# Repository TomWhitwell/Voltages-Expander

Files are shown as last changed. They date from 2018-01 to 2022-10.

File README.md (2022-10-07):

# Voltages Expander for the Turing Machine 

Hardware documentation for the old Voltages Fader Expander for the Music Thing Modular Turing Machine, published CC-BY-SA. 

For more details, visit http://www.musicthing.co.uk/

Qty | Value | Device | Parts | Description | Mouser
-- | -- | -- | -- | -- | --
8 | 50k | Illuminated Fader | GATE1, GATE2, GATE3, GATE4, GATE5, GATE6, GATE7, GATE8 | 20mm Alpha Illuminated Fader | 312-2045F-R50K
1 | 10k | 9mm pot | SCALE | 9 mm vertical pot, D shaft | 688-RK09K1130AH1
1 | 50k | 9mm pot | OFFSET | 9 mm vertical pot, D shaft | 652-PTV09A-4025FB503
2 | 100n | C-EU025-024X044 | C1, C2 | CAPACITOR | 594-K104K15X7RF5TH5
1 | TL074 | TL074 | IC1 | OP AMP | 595-TL074CN
1 |   | MA08-2 | GATES | PIN HEADER 2x8 | 649-67997-216HLF
1 | 78L09 |   | 78L1 | Positive VOLTAGE REGULATOR | 511-L78L09ACZ
6 | 10k | R-EU_0207/10 | R3, R4, R5, R6, R7, R8 | RESISTOR | 660-MF1/4DCT52A1002F
4 | 1k | R-EU_0207/10 | R1, R2, R9, R10 | RESISTOR | 660-MF1/4DCT52R1001F
1 | 10k | RN08 | RN1 | Resistor Network 9 pin, 8 resistors, bussed | 652-4609X-1LF-10K
1 | 2k | RN08 | RN2 | Resistor Network 9 pin, 8 resistors, bussed | 652-4609X-1LF-2K
3 | PJ-301B | PJ-301B | CLOCK_OUT, INVERT_OUT, MAIN_OUT | Sockets | Available from Erthenvar or Thonk
1 |   |   | 14 pin DIP socket |   | 649-DILB14P-223TLF
  |   |   |   |   |

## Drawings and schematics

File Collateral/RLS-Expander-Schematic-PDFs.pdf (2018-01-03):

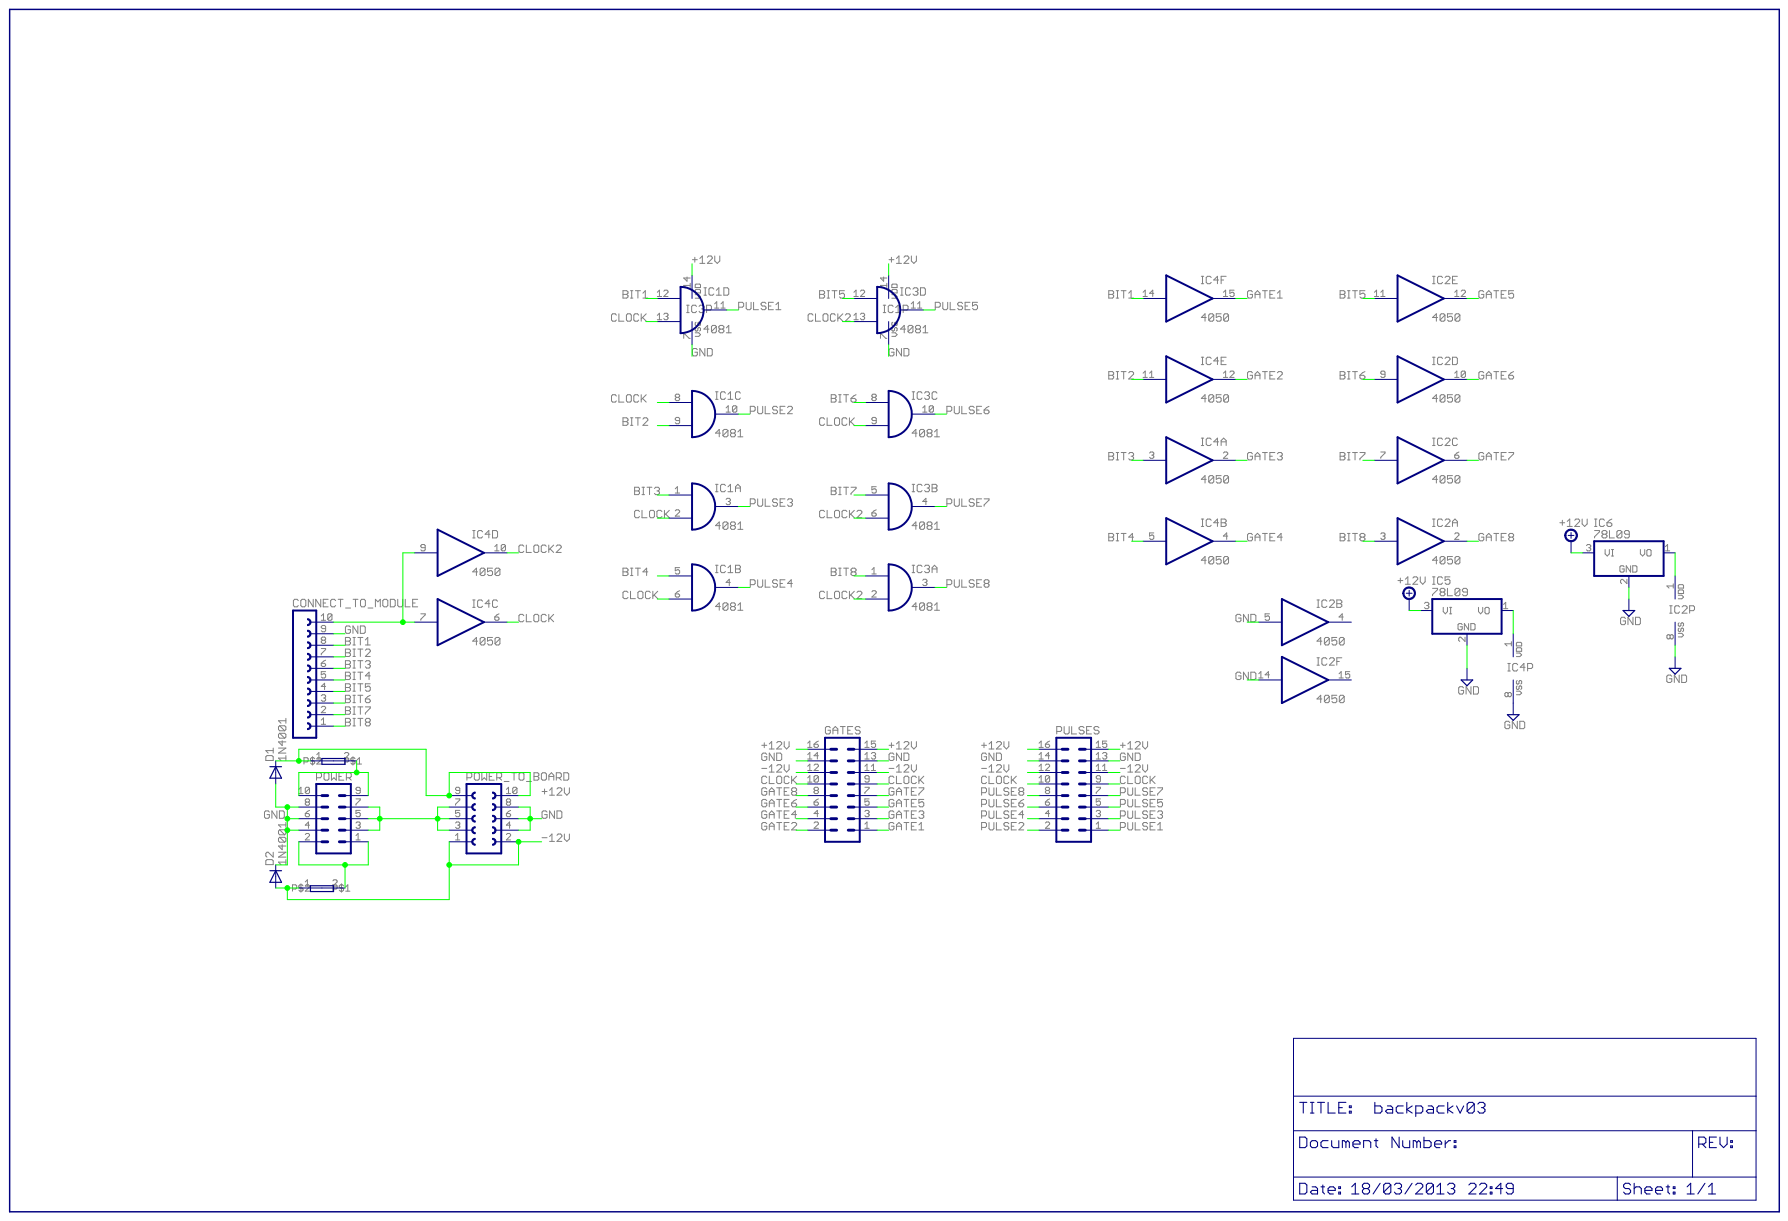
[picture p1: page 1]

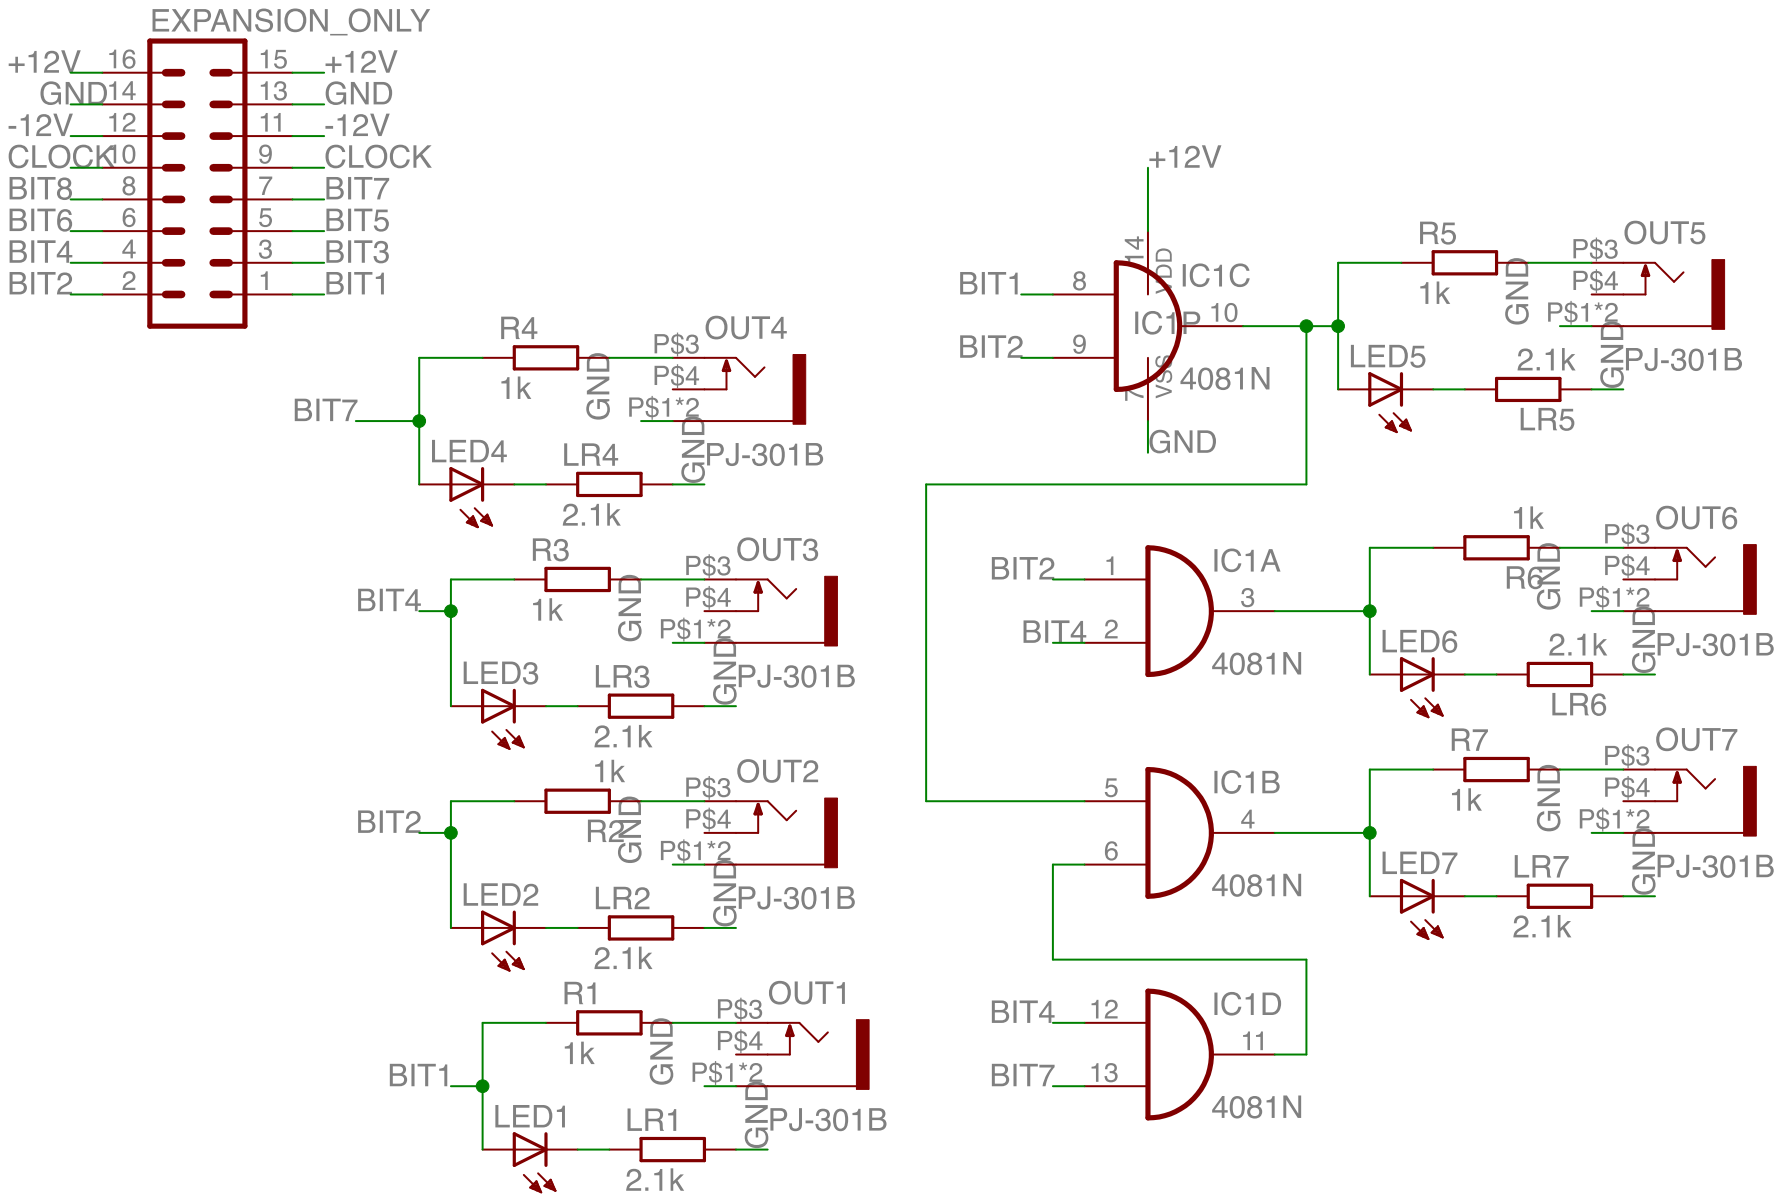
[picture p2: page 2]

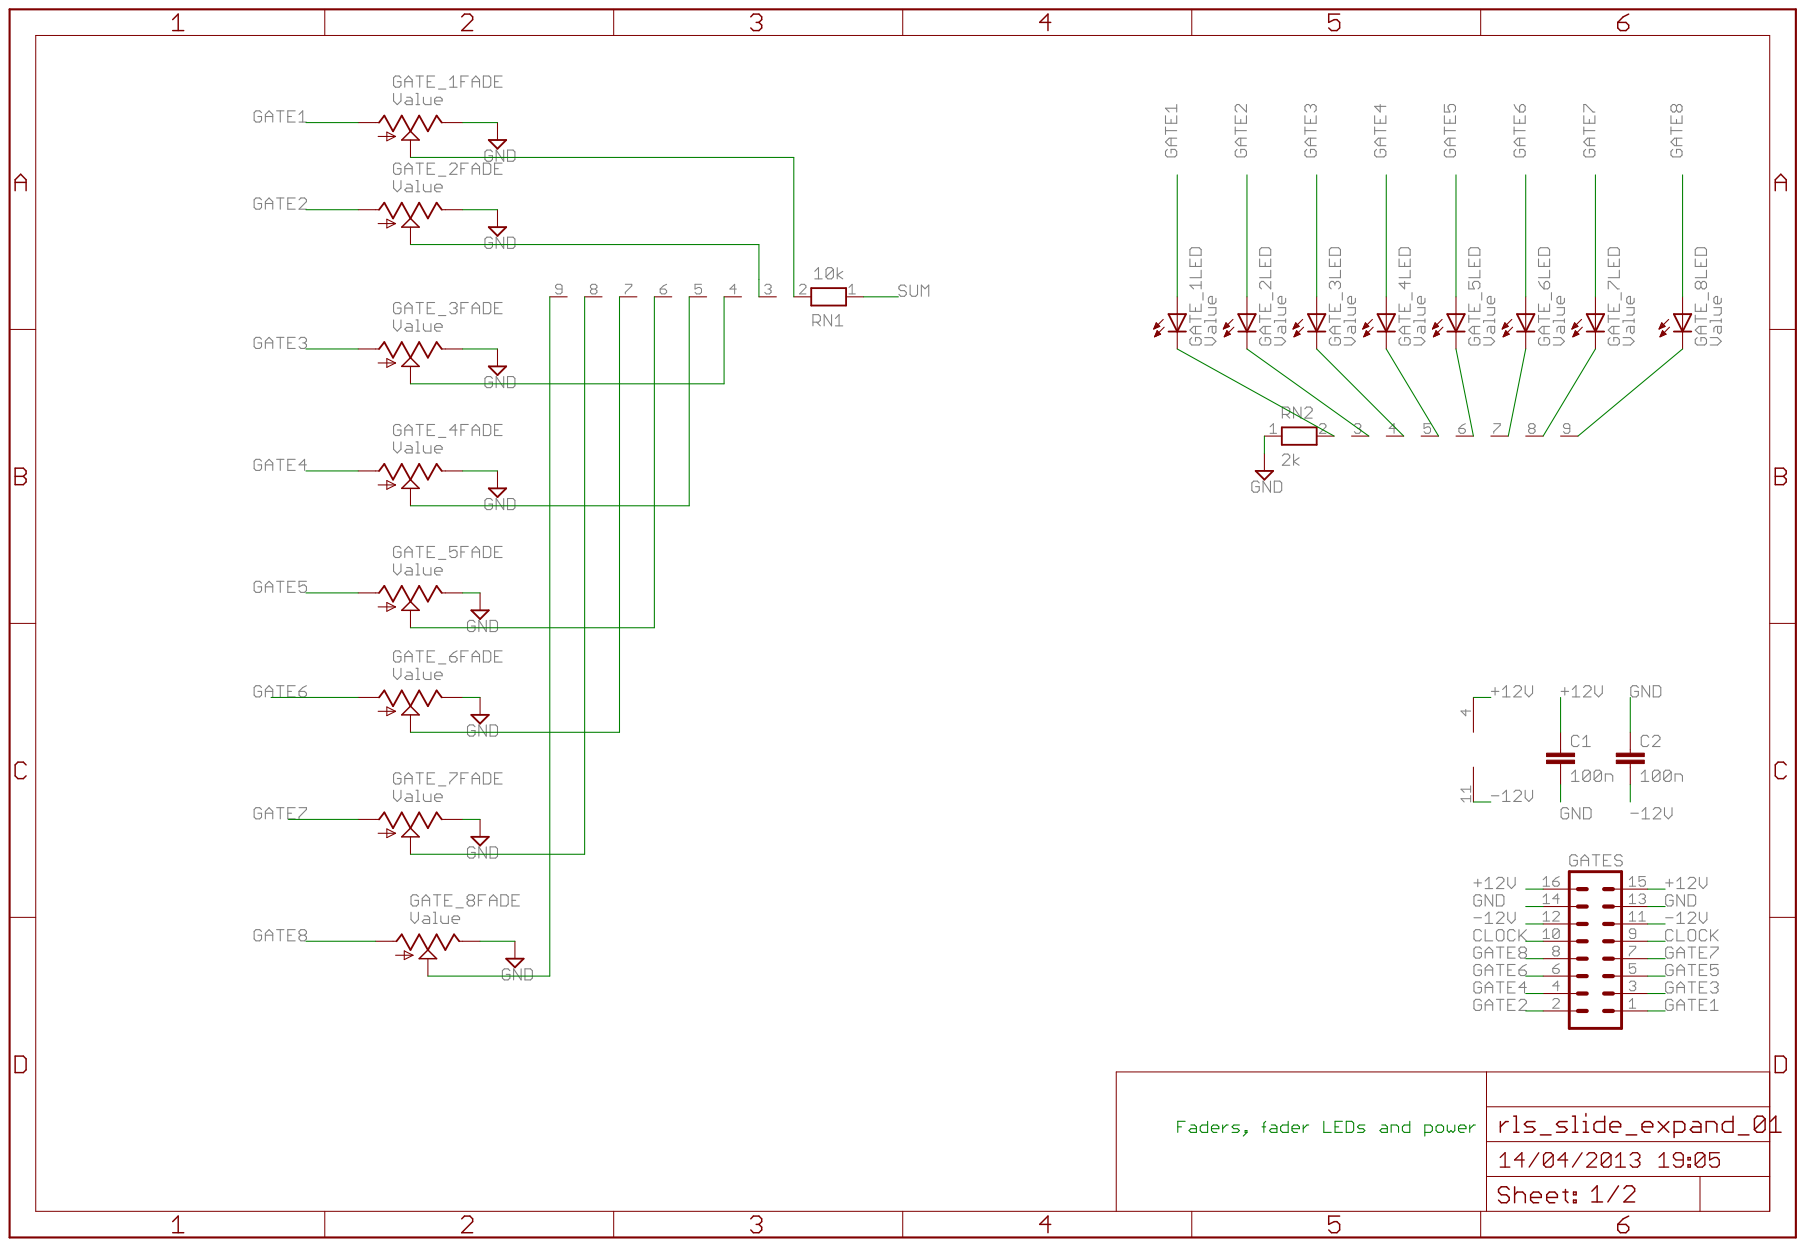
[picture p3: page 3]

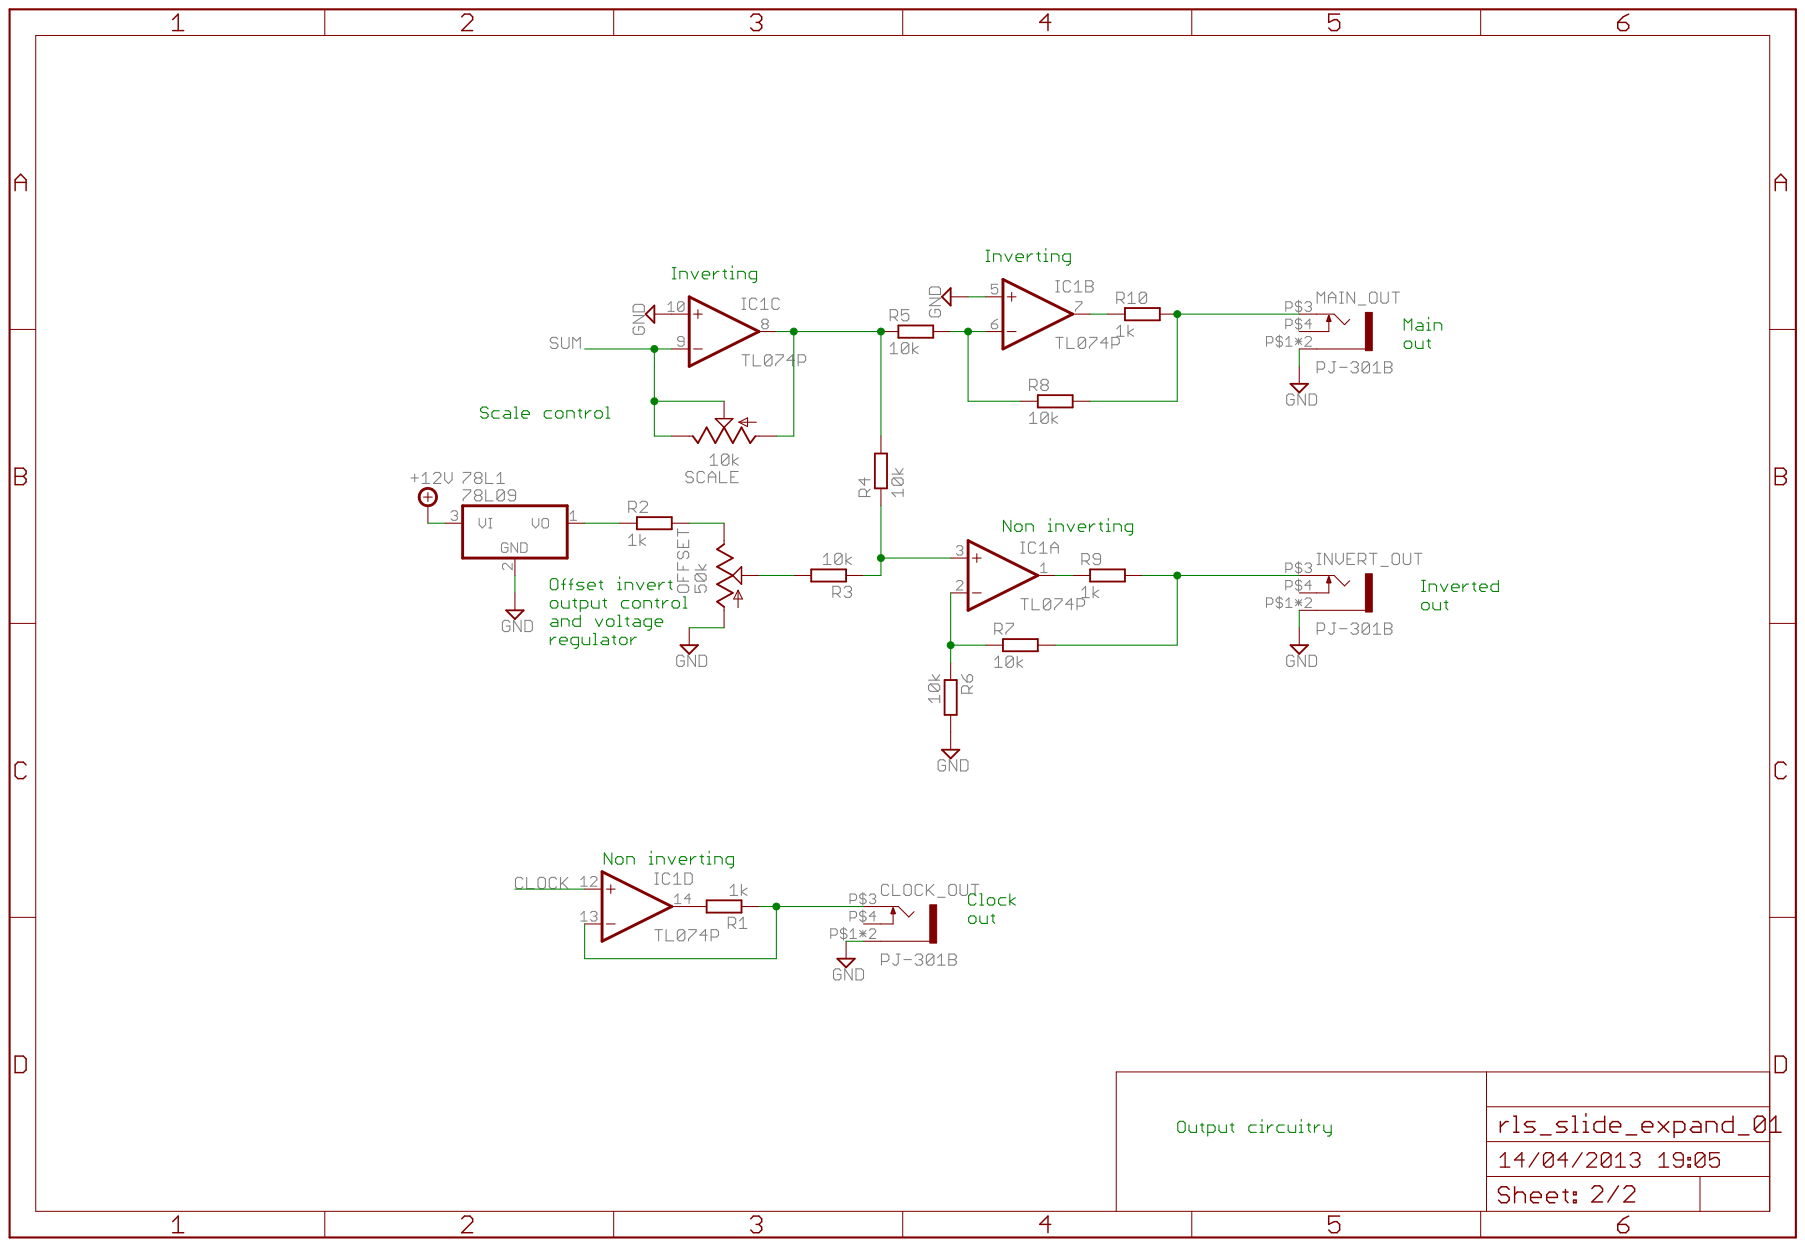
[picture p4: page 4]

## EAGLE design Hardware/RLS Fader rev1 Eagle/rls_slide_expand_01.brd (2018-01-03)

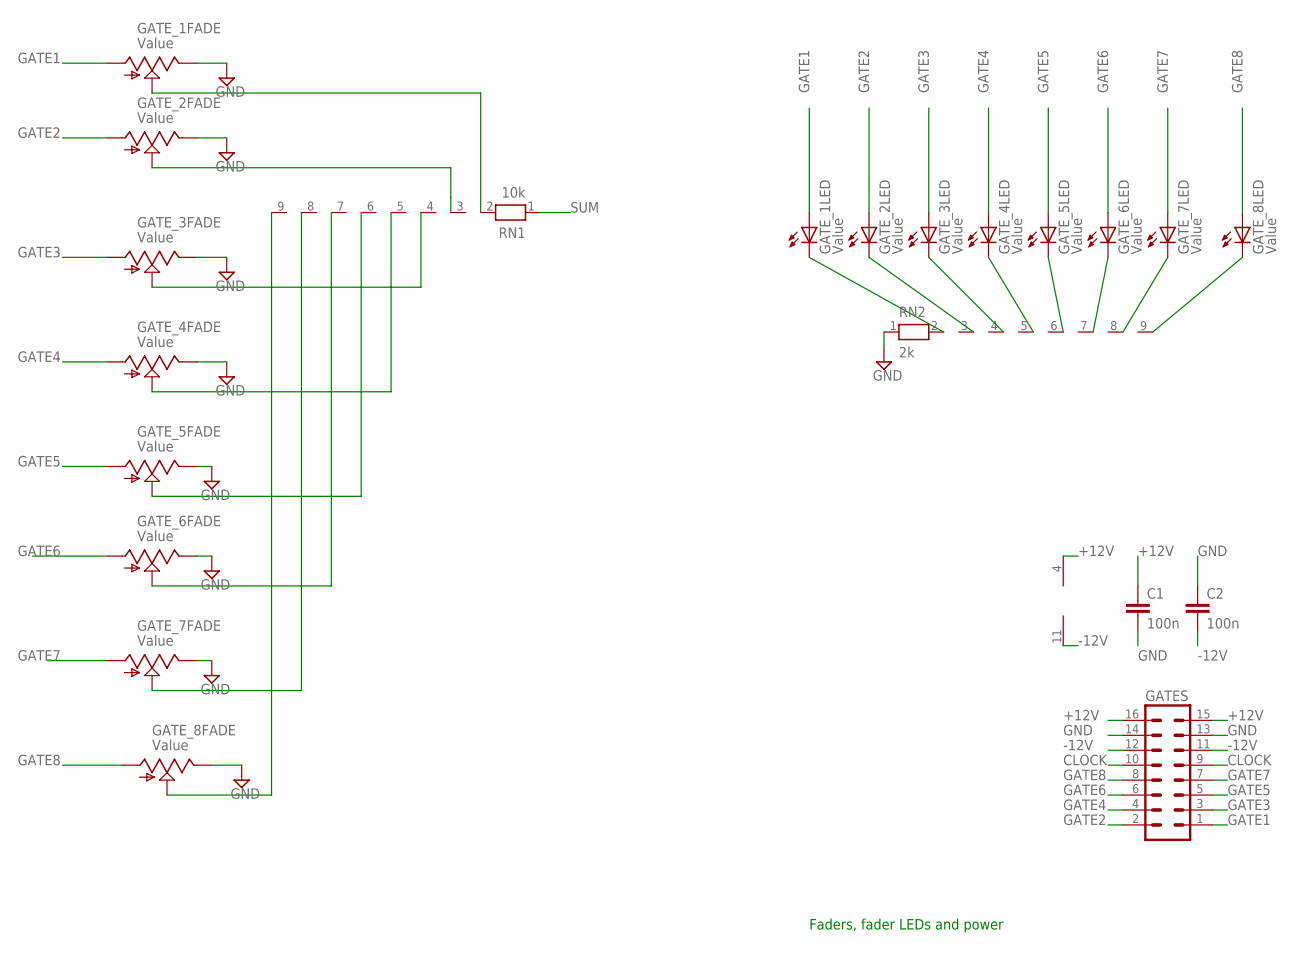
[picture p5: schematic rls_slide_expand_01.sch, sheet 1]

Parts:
C1, C2: 100n; C050-024X044
GATES: MA08-2
GATE_1, GATE_2, GATE_3, GATE_4, GATE_5, GATE_6, GATE_7, GATE_8: Value; ALPHA_ILL_FADER_20MM
IC1: TL074P; DIL14
RN1: 10k; RN-9
RN2: 2k; RN-9

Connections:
+12V: C1.1, GATES.15, GATES.16, IC1.4 (V+); also elsewhere on the board
-12V: C2.2, GATES.11, GATES.12, IC1.11 (V-)
CLOCK: GATES.9, GATES.10; also elsewhere on the board
GATE1: GATES.1, GATE_1.3 (A), GATE_1.B (A)
GATE2: GATES.2, GATE_2.3 (A), GATE_2.B (A)
GATE3: GATES.3, GATE_3.3 (A), GATE_3.B (A)
GATE4: GATES.4, GATE_4.3 (A), GATE_4.B (A)
GATE5: GATES.5, GATE_5.3 (A), GATE_5.B (A)
GATE6: GATES.6, GATE_6.3 (A), GATE_6.B (A)
GATE7: GATES.7, GATE_7.3 (A), GATE_7.B (A)
GATE8: GATES.8, GATE_8.3 (A), GATE_8.B (A)
GND: C1.2, C2.1, GATES.13, GATES.14, GATE_1.1 (E), GATE_2.1 (E), GATE_3.1 (E), GATE_4.1 (E), GATE_5.1 (E), GATE_6.1 (E), GATE_7.1 (E), GATE_8.1 (E), RN2.1; also elsewhere on the board
unnamed: GATE_1.2 (S), RN1.2
unnamed: GATE_1.E (C), RN2.2
unnamed: GATE_2.2 (S), RN1.3
unnamed: GATE_2.E (C), RN2.3
unnamed: GATE_3.E (C), RN2.4
unnamed: GATE_3.2 (S), RN1.4
unnamed: GATE_4.2 (S), RN1.5
unnamed: GATE_5.2 (S), RN1.6
unnamed: GATE_6.2 (S), RN1.7
unnamed: GATE_7.2 (S), RN1.8
unnamed: GATE_8.2 (S), RN1.9
unnamed: GATE_4.E (C), RN2.5
unnamed: GATE_6.E (C), RN2.7
unnamed: GATE_5.E (C), RN2.6
unnamed: GATE_7.E (C), RN2.8
unnamed: GATE_8.E (C), RN2.9
SUM: RN1.1; also elsewhere on the board

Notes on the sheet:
Faders, fader LEDs and power

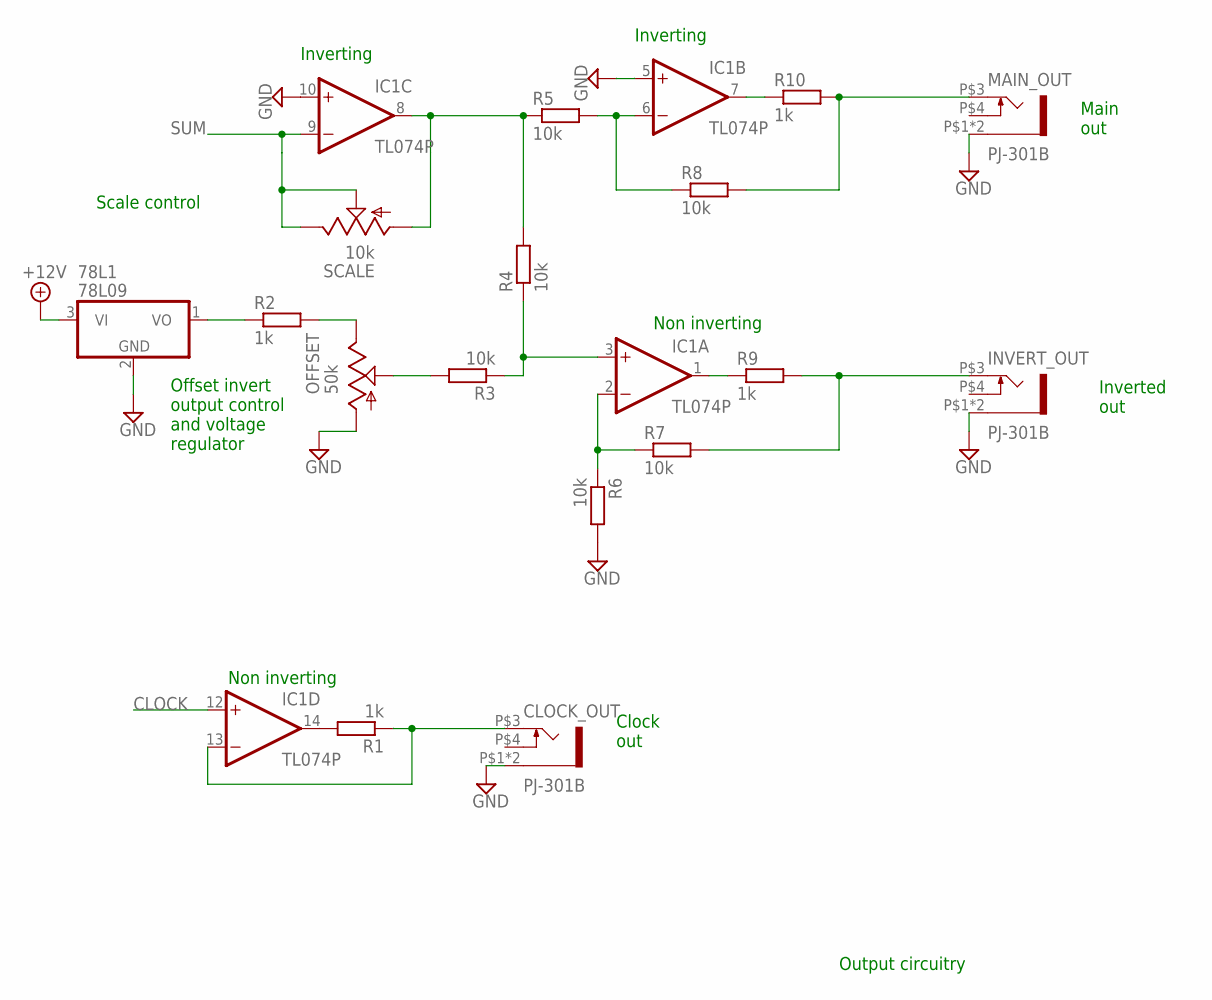
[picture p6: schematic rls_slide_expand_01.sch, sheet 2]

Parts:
78L1: 78L09; TO92
CLOCK_OUT: PJ-301B
IC1: TL074P; DIL14
INVERT_OUT: PJ-301B
MAIN_OUT: PJ-301B
OFFSET: 50k; EVUF
R1, R2, R9, R10: 1k; 0207/10
R3, R4, R5, R6, R7, R8: 10k; 0207/10
SCALE: 10k; EVUF

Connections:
+12V: 78L1.3 (VI); also elsewhere on the board
CLOCK: IC1.12 (+IN); also elsewhere on the board
GND: 78L1.2 (GND), CLOCK_OUT.P$1 (5), CLOCK_OUT.P$2 (5), IC1.5 (+IN), IC1.10 (+IN), INVERT_OUT.P$1 (5), INVERT_OUT.P$2 (5), MAIN_OUT.P$1 (5), MAIN_OUT.P$2 (5), OFFSET.1 (A), R6.2; also elsewhere on the board
unnamed: IC1.6 (-IN), R5.2, R8.1
unnamed: MAIN_OUT.P$3 (3), R8.2, R10.2
unnamed: IC1.7 (OUT), R10.1
unnamed: OFFSET.3 (E), R2.2
unnamed: IC1.1 (OUT), R9.1
unnamed: OFFSET.2 (S), R3.2
unnamed: IC1.3 (+IN), R3.1, R4.1
unnamed: IC1.2 (-IN), R6.1, R7.1
unnamed: INVERT_OUT.P$3 (3), R7.2, R9.2
unnamed: IC1.8 (OUT), R4.2, R5.1, SCALE.1 (A)
unnamed: IC1.14 (OUT), R1.2
unnamed: CLOCK_OUT.P$3 (3), IC1.13 (-IN), R1.1
unnamed: 78L1.1 (VO), R2.1
SUM: IC1.9 (-IN), SCALE.2 (S), SCALE.3 (E); also elsewhere on the board

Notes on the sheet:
Scale control
Offset invert output control and voltage regulator
Main out
Inverted out
Clock out
Output circuitry
Inverting
Non inverting

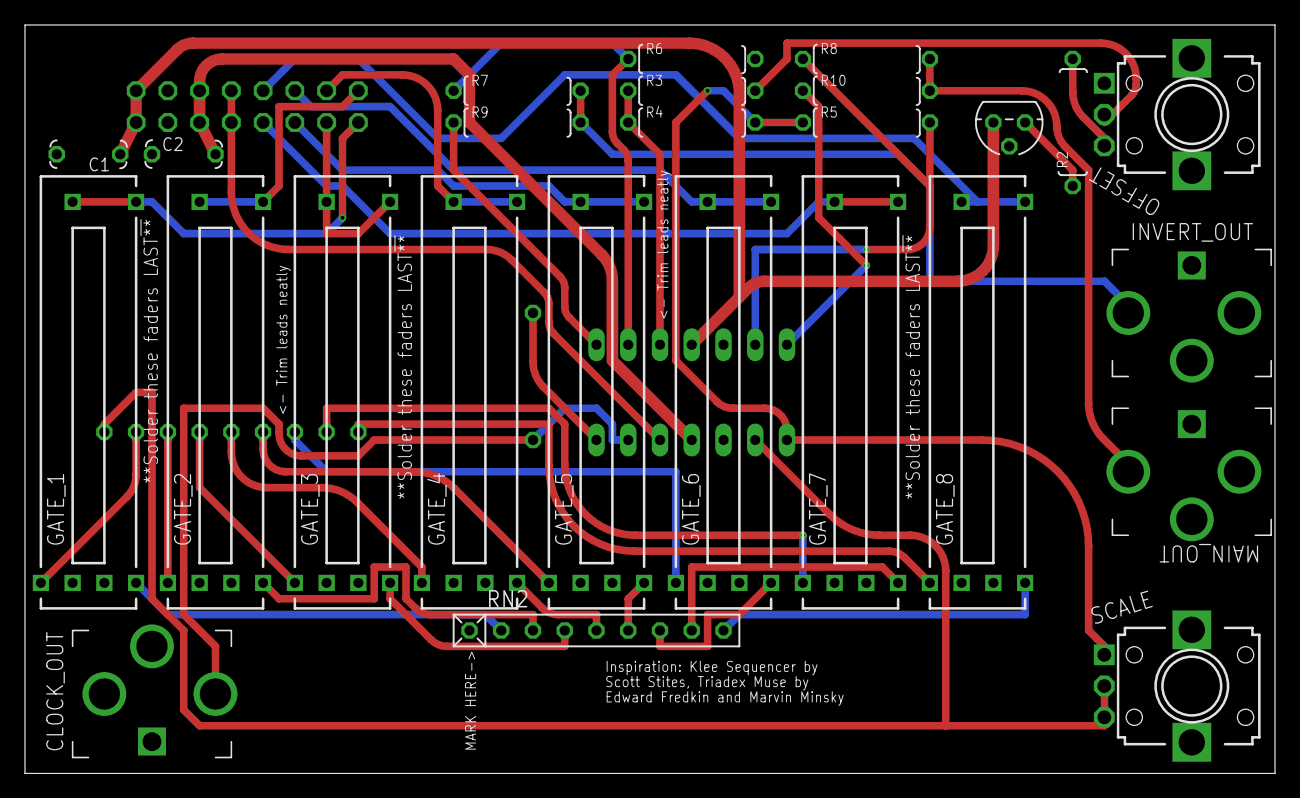
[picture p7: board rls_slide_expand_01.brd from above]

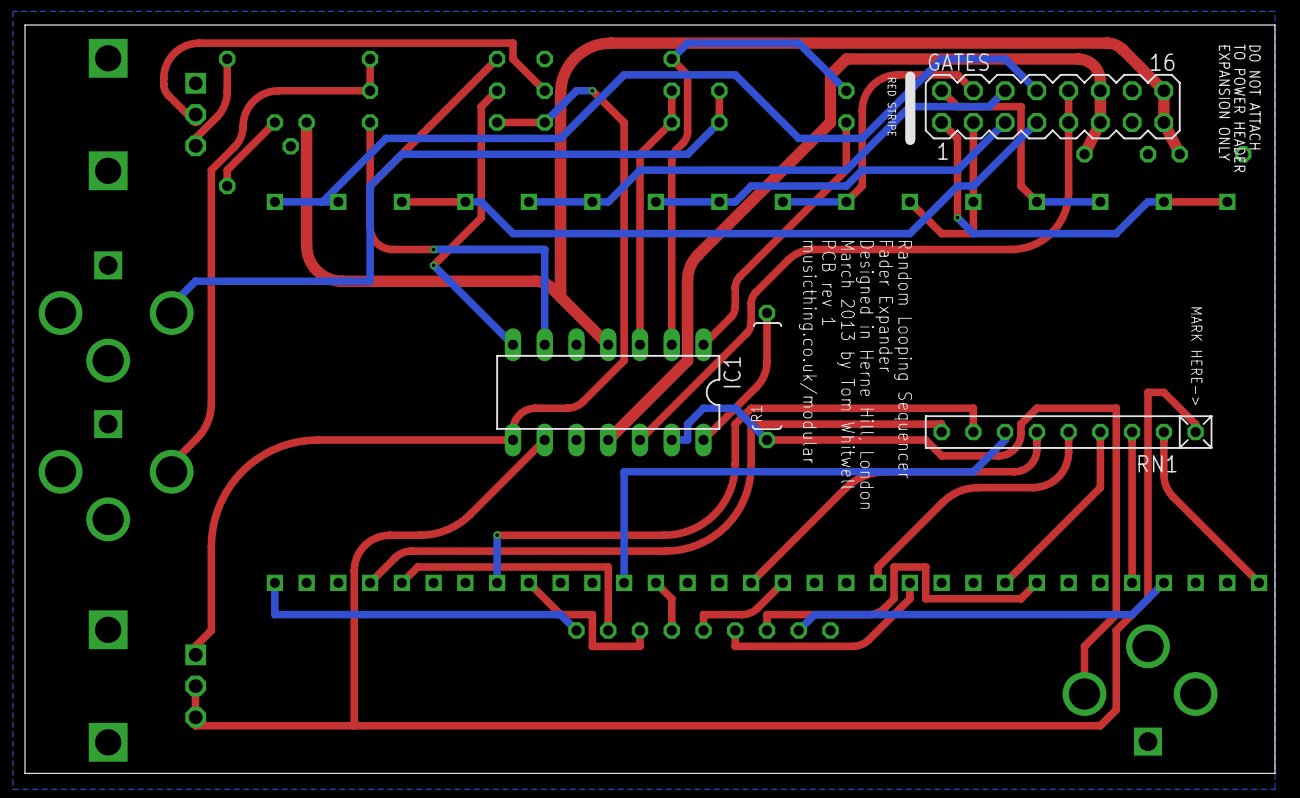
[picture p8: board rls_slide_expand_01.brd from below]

Board: 2 copper layers, 100.0 x 59.9 mm, 30 parts (4 on the bottom side), 42 nets.

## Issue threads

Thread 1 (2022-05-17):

BOM available?

FlorianO, 2022-05-17:
Hey, can you add a BOM to the repo?
I only have a PCB and a panel. :(

FlorianO, 2022-10-07:
I got the board from someone who haden't the materials anymore.

TomWhitwell, 2022-10-07:
Sorry for the delay

Qty | Value | Device | Parts | Description | Mouser
-- | -- | -- | -- | -- | --
8 | 50k | Illuminated Fader | GATE1, GATE2, GATE3, GATE4, GATE5, GATE6, GATE7, GATE8 | 20mm Alpha Illuminated Fader | 312-2045F-R50K
1 | 10k | 9mm pot | SCALE | 9 mm vertical pot, D shaft | 688-RK09K1130AH1
1 | 50k | 9mm pot | OFFSET | 9 mm vertical pot, D shaft | 652-PTV09A-4025FB503
2 | 100n | C-EU025-024X044 | C1, C2 | CAPACITOR | 594-K104K15X7RF5TH5
1 | TL074 | TL074 | IC1 | OP AMP | 595-TL074CN
1 |   | MA08-2 | GATES | PIN HEADER 2x8 | 649-67997-216HLF
1 | 78L09 |   | 78L1 | Positive VOLTAGE REGULATOR | 511-L78L09ACZ
6 | 10k | R-EU_0207/10 | R3, R4, R5, R6, R7, R8 | RESISTOR | 660-MF1/4DCT52A1002F
4 | 1k | R-EU_0207/10 | R1, R2, R9, R10 | RESISTOR | 660-MF1/4DCT52R1001F
1 | 10k | RN08 | RN1 | Resistor Network 9 pin, 8 resistors, bussed | 652-4609X-1LF-10K
1 | 2k | RN08 | RN2 | Resistor Network 9 pin, 8 resistors, bussed | 652-4609X-1LF-2K
3 | PJ-301B | PJ-301B | CLOCK_OUT, INVERT_OUT, MAIN_OUT | Sockets | Available from Erthenvar or Thonk
1 |   |   | 14 pin DIP socket |   | 649-DILB14P-223TLF
  |   |   |   |   |  

Qty	Value	Device	Parts	Description	Mouser
8	50k	Illuminated Fader	GATE1, GATE2, GATE3, GATE4, GATE5, GATE6, GATE7, GATE8	20mm Alpha Illuminated Fader	312-2045F-R50K
1	10k	9mm pot	SCALE	9 mm vertical pot, D shaft	688-RK09K1130AH1
1	50k	9mm pot	OFFSET	9 mm vertical pot, D shaft	652-PTV09A-4025FB503
2	100n	C-EU025-024X044	C1, C2	CAPACITOR	594-K104K15X7RF5TH5
1	TL074	TL074	IC1	OP AMP	[595-TL074CN](https://uk.mouser.com/Search/ProductDetail.aspx?R=TL074CNvirtualkey59500000virtualkey595-TL074CN)
1		MA08-2	GATES	PIN HEADER 2x8	[649-67997-216HLF](https://uk.mouser.com/Search/ProductDetail.aspx?R=67997-216HLFvirtualkey64910000virtualkey649-67997-216HLF)
1	78L09		78L1	Positive VOLTAGE REGULATOR	511-L78L09ACZ
6	10k	R-EU_0207/10	R3, R4, R5, R6, R7, R8	RESISTOR	[660-MF1/4DCT52A1002F](https://uk.mouser.com/Search/ProductDetail.aspx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)
4	1k	R-EU_0207/10	R1, R2, R9, R10	RESISTOR	[660-MF1/4DCT52R1001F](https://uk.mouser.com/Search/ProductDetail.aspx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)
1	10k	RN08	RN1	Resistor Network 9 pin, 8 resistors, bussed	[652-4609X-1LF-10K](https://uk.mouser.com/Search/ProductDetail.aspx?R=4609X-101-103LFvirtualkey65210000virtualkey652-4609X-1LF-10K)
1	2k	RN08	RN2	Resistor Network 9 pin, 8 resistors, bussed	652-4609X-1LF-2K
3	PJ-301B	PJ-301B	CLOCK_OUT, INVERT_OUT, MAIN_OUT	Sockets	Available from Erthenvar or Thonk
1			14 pin DIP socket 		[649-DILB14P-223TLF](https://uk.mouser.com/Search/ProductDetail.aspx?R=DILB14P-223TLFvirtualkey64910000virtualkey649-DILB14P-223TLF)

FlorianO, 2022-10-07:
Thank you so much. :)

Closed 2022-10-07.

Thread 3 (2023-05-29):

suddenly every even gate has no output and no light

raimund, 2023-05-29:
What can cause this behaviour? It‘s mk2 voltages expander and every second slider does not light up and also does not output any value. What could be broken?

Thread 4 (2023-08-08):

Change resistor network to 100k for more linear response

TomWhitwell, 2023-08-08:
I am sure you are aware that – despite having linear taper – the sliders in “Voltages” have a very non-linear response in circuit, due to the loading effect of the elements of the 10k Resistor network.

From Paul Darlington:

I wonder if you were aware of this non-linearity and left it in place during the design (I can see at least one reason why it might be seen as desirable) or if it was ‘unintentional’?

My habit is to use Voltages by placing the sliders at or near ‘semitone’ locations (usually having first set SCALE such that the whole travel of a single slider gives an octave pitch change / 1V CV change).

This, along with the non-linearity mentioned above, places 13 semitones ‘awkwardly’ along the slider, with most of the squeezed up at the right-hand end…

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

So – given my preferred way of using Voltages - the non-linearity is a nuisance.

On paper, it seemed rather easy to rectify this by changing the resistor network for one with 100k value and making a similar change to the SCALE potentiometer from 10k to 100k. Of course, swapping out the resistor network in an existing Voltages module is not practical so …

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

I have purchased  a second Voltages module from Thonk and made the proposed modification yesterday – it works as predicted – the semitones now appear exactly as theory predicts (close enough to a linear disposition along the slider travel)…
